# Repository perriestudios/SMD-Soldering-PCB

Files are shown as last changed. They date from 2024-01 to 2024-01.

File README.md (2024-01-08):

# EE201 - Computer Hardware Skills

## SMD Soldering Practice Board

This PCB was designed with the goal of teaching students how to solder surface mount components. 

### Logic
The core logic of the circuit is the logic gates NOT, AND, OR and XOR. There is a multiplexer the outputs of one of these gates to the LED used for indication.

### Inputs
Power supply for the PCB is through a Type-C USB.

There are two tactile switches (push buttons), used to emulate the inputs A and B for the logic gates. The circuit is in active-high configuration with a weak pull-down resistor of 1k. This value was chosen to consolidate the BOM and limit the number of unique resistors(since LEDs also need current limiting resistors).

A DIP Switch is used to set the MUX configuration of Enable, S0 and S1. The other two inputs of the DIP switch can be used as a back up for inputs A and B.

### More SMT Packages Section

This section is used to provide an overview of some commonly available SMD packages of Passives, Transistors and ICs. Students will not solder this, it is just to give them a feel of how big components are.

### Packages that Students will be Soldering

- Resistors: 0805 and 1206
- LED: 1206
- Logic Gates: SOT323
- MUX: SOIC16
- Capacitor - 0603
- Tactile Switches - 6mmx6mm
- DIP Switch - 2.54mm pitch

### Design Choices

In the process of completing this design, there were several tradeoffs and decisions made. The biggest factor influencing the choices was a circuit of reasonable complexity for Sophomores to solder in approximately 1 hour.

- Logic gates were chosen as the design as it would be intuitive and fun. Some of the other ideas considered were a Digital Dice, Digital Modulator(PPM, PWM, PAM), a device that would indicate a threshold (temperature, etc).
- Limited the number of components to 15
- Limited the package size to 0805

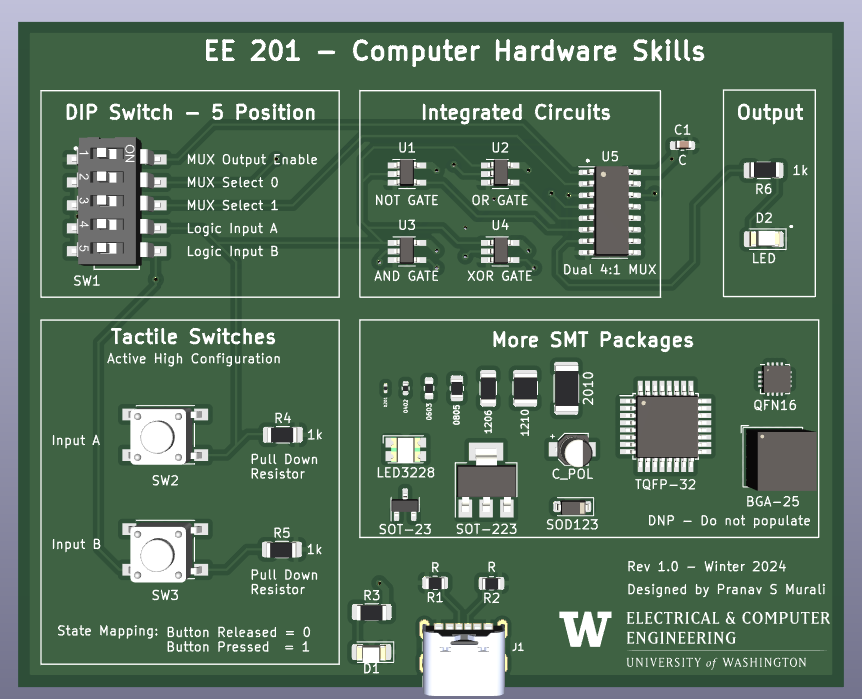
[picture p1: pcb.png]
3D View of the PCB


### Possible improvements

- Wanted to interface an RGB Led, but didn't proceed considering cost and complexity of soldering.
- Find a way to control the routing of inputs of the logic gates. Currently there is only routing over the outputs. The logic gates will be draining power unnecessarily.
- Instead of using an off the shelf IC, one of the gates could be replaced with an actual TTL implementation. NOT gate would be the easiest.

### Acknowledgement

This design was inspired by [Educational Logic Gates PCB](https://www.pcbway.com/project/shareproject/Educational_logic_gates_PCB.html)

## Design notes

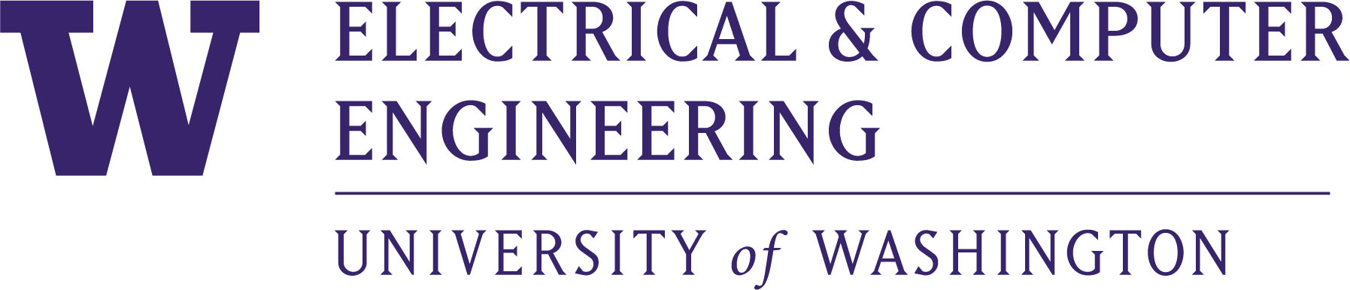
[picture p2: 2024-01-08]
ECE_UW_stack_purp.jpg

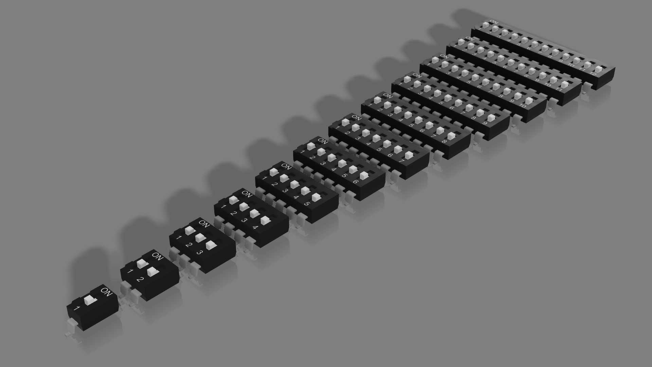
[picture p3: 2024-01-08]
3D Models/smd-dip-switches-1.snapshot.2/SMD DIP SWITCH RENDER.png

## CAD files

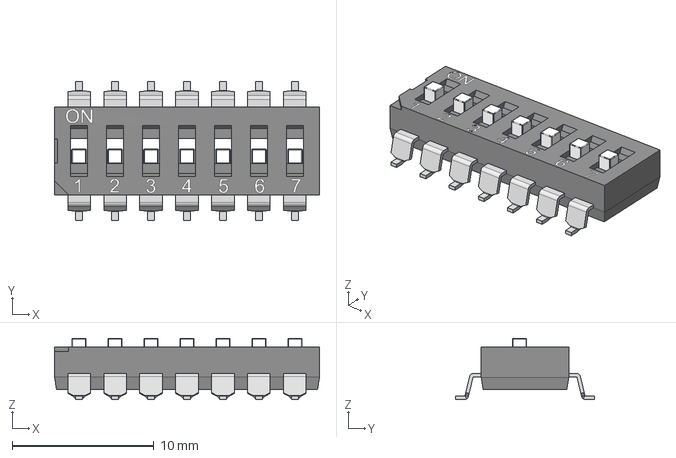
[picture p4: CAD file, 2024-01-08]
3D Models/smd-dip-switches-1.snapshot.2/SMD DIP SWITCH 7P.step
18.7 x 9.80 x 4.32 mm

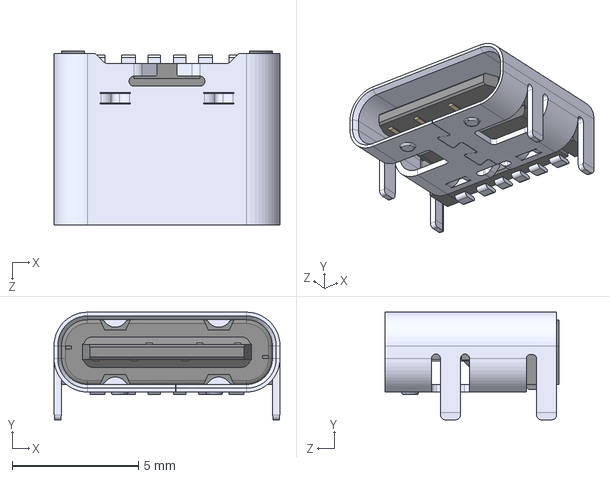
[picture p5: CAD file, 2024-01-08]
3D Models/UJC-HP-3-SMT-TR--3DModel-STEP-56544.STEP
8.94 x 4.26 x 6.90 mm

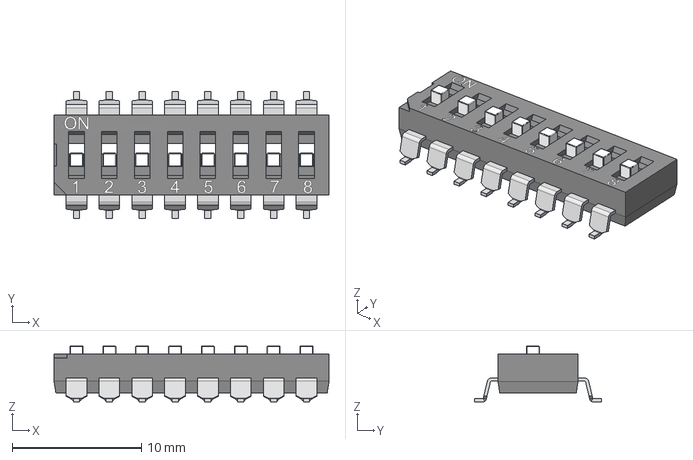
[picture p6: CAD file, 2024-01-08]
3D Models/smd-dip-switches-1.snapshot.2/SMD DIP SWITCH 8P.step
21.3 x 9.80 x 4.32 mm

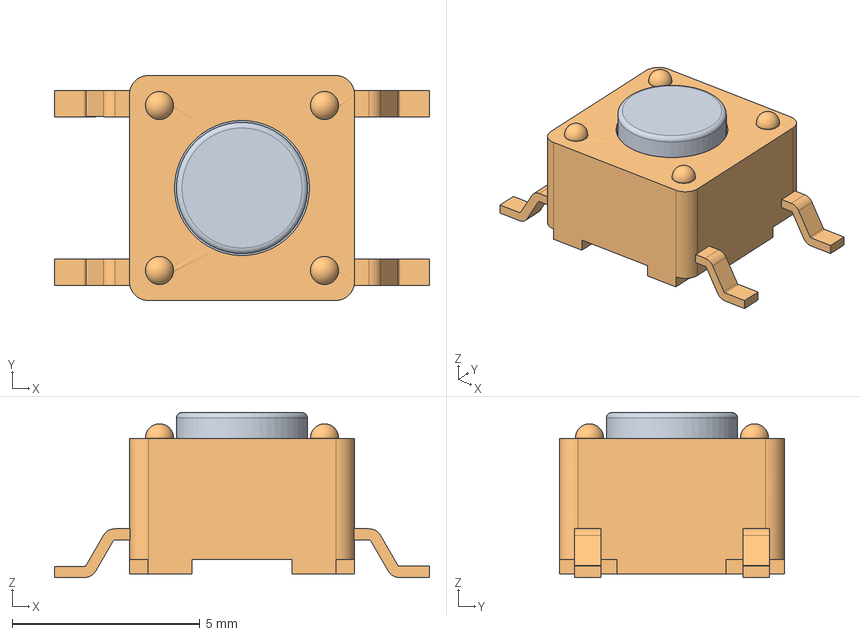
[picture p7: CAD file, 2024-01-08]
3D Models/TL3301NF160QG--3DModel-STEP-520916.STEP
10.0 x 6.00 x 4.40 mm

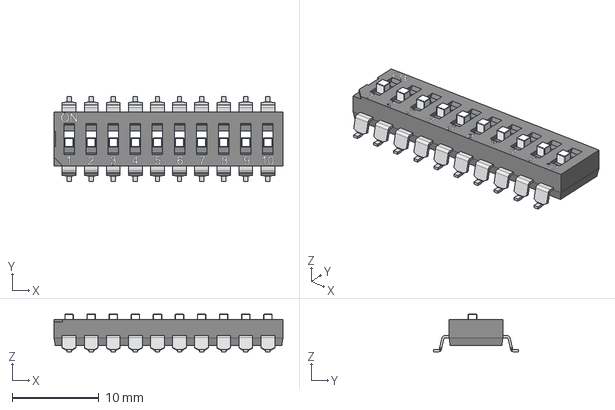
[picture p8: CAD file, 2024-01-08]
3D Models/smd-dip-switches-1.snapshot.2/SMD DIP SWITCH 10P.step
26.3 x 9.80 x 4.32 mm

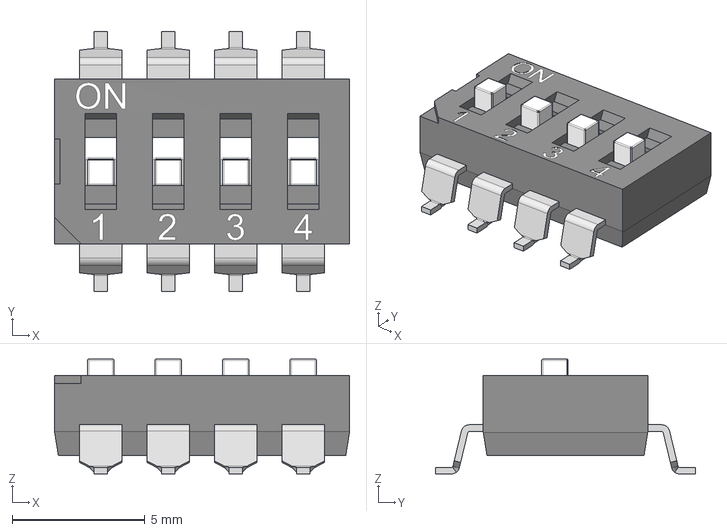
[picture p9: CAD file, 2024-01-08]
3D Models/smd-dip-switches-1.snapshot.2/SMD DIP SWITCH 4P.step
11.1 x 9.80 x 4.32 mm

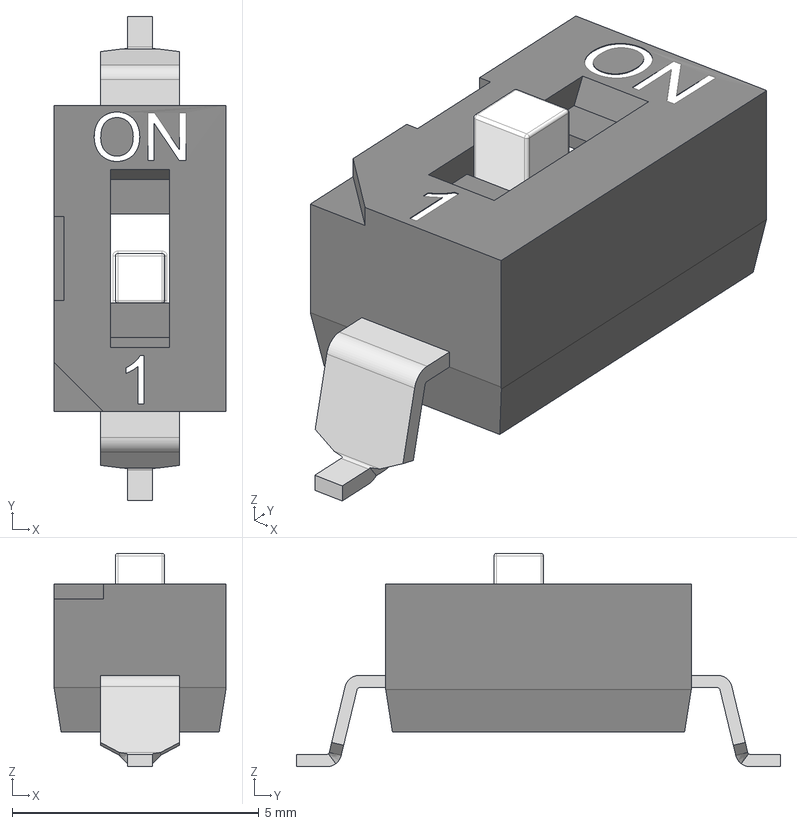
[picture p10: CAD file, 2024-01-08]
3D Models/smd-dip-switches-1.snapshot.2/SMD DIP SWITCH 1P.step
3.48 x 9.80 x 4.32 mm

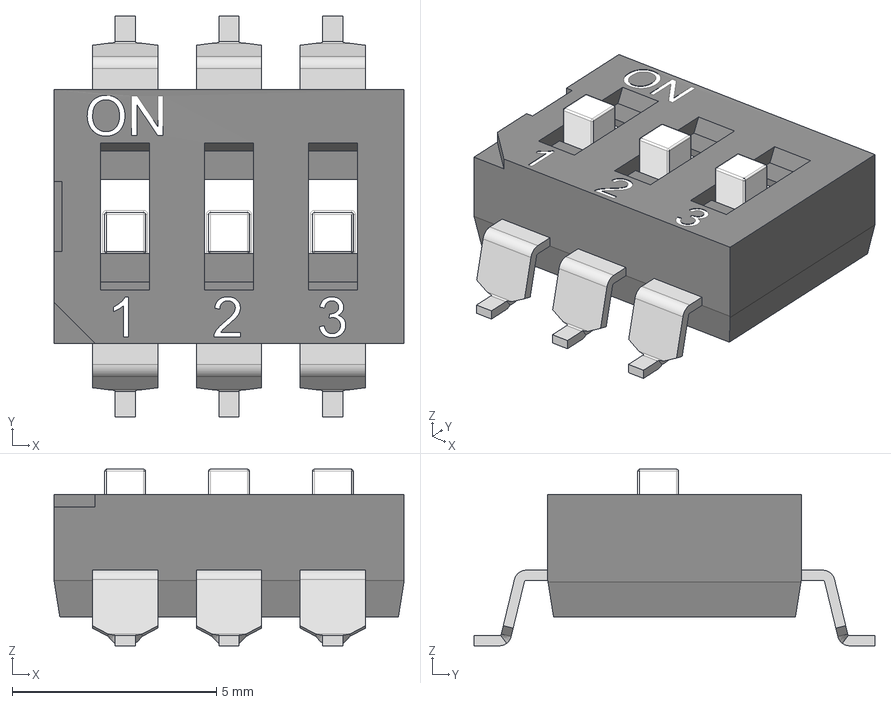
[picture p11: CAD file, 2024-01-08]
3D Models/smd-dip-switches-1.snapshot.2/SMD DIP SWITCH 3P.step
8.56 x 9.80 x 4.32 mm

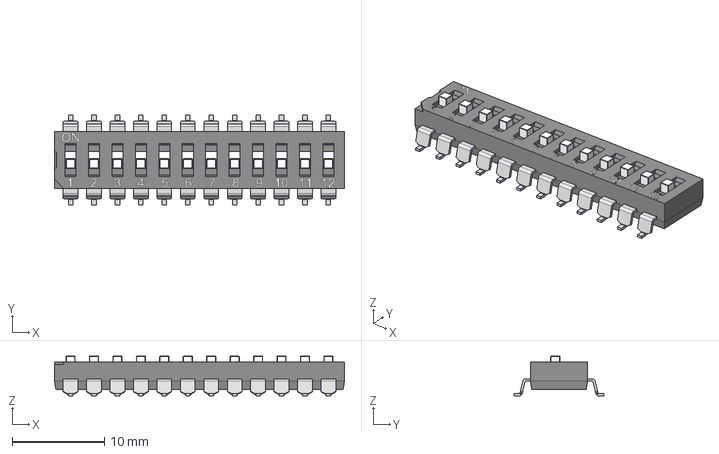
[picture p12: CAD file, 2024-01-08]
3D Models/smd-dip-switches-1.snapshot.2/SMD DIP SWITCH 12P.step
31.4 x 9.80 x 4.32 mm

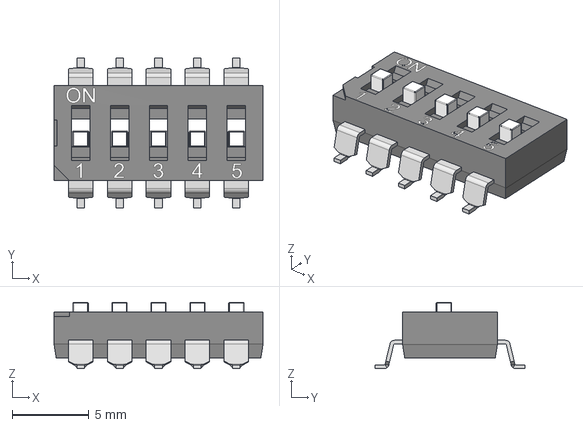
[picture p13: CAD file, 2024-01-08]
3D Models/smd-dip-switches-1.snapshot.2/SMD DIP SWITCH 5P.step
13.6 x 9.80 x 4.32 mm

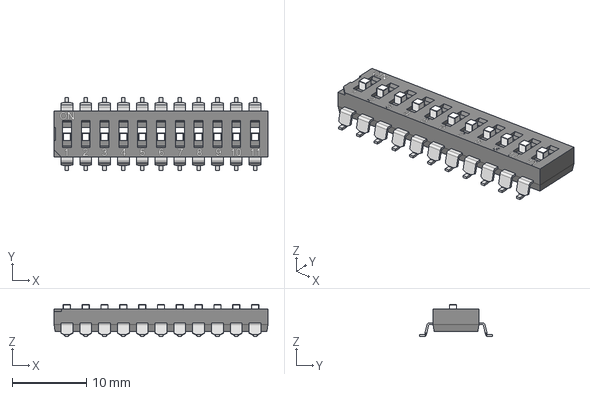
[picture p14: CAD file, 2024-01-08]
3D Models/smd-dip-switches-1.snapshot.2/SMD DIP SWITCH 11P.step
28.9 x 9.80 x 4.32 mm

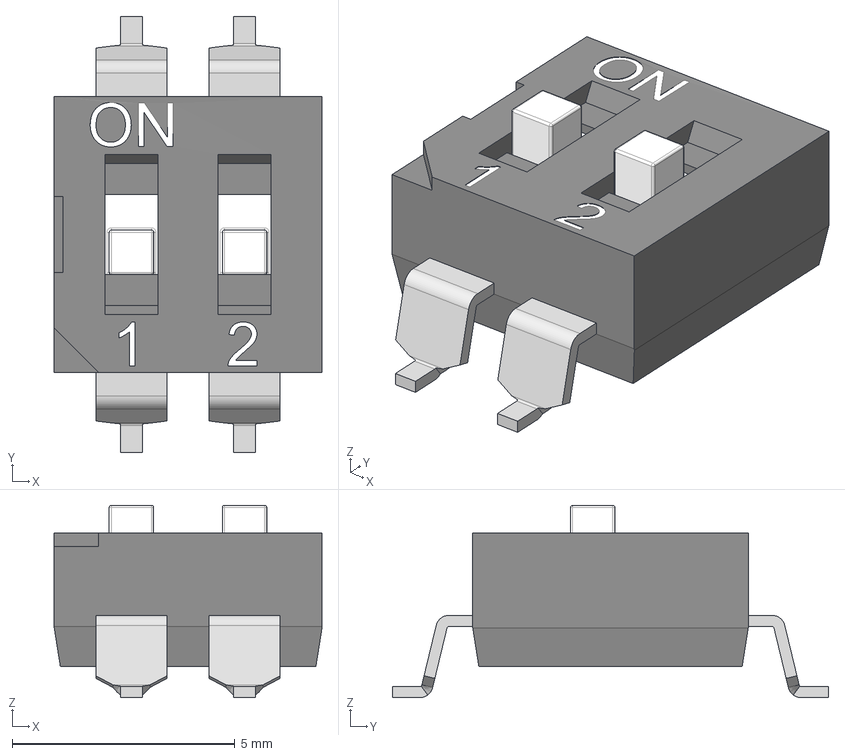
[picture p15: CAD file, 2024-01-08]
3D Models/smd-dip-switches-1.snapshot.2/SMD DIP SWITCH 2P.step
6.02 x 9.80 x 4.32 mm

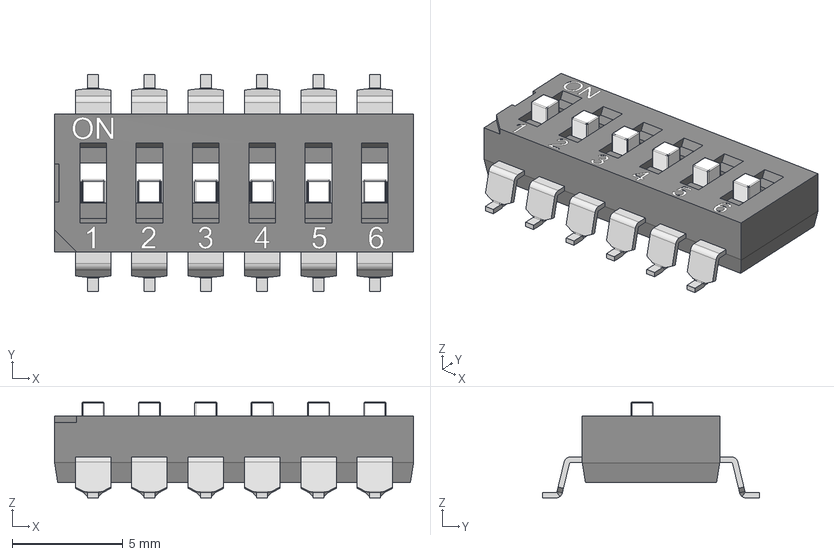
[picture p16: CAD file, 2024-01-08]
3D Models/smd-dip-switches-1.snapshot.2/SMD DIP SWITCH 6P.step
16.2 x 9.80 x 4.32 mm

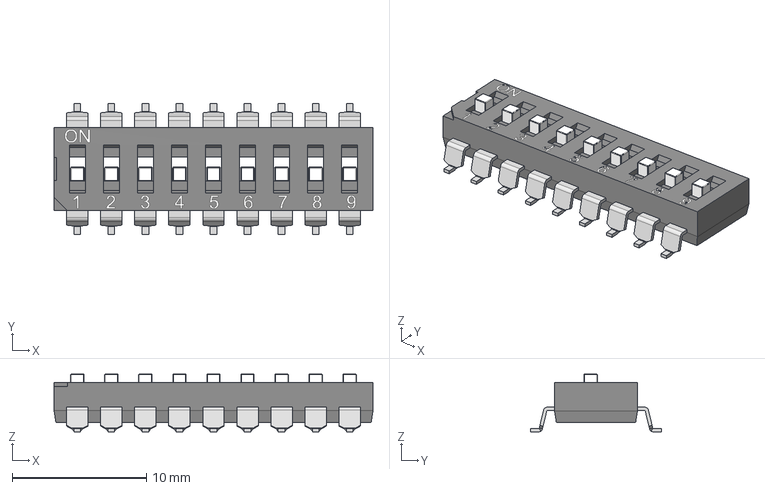
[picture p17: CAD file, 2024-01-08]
3D Models/smd-dip-switches-1.snapshot.2/SMD DIP SWITCH 9P.step
23.8 x 9.80 x 4.32 mm

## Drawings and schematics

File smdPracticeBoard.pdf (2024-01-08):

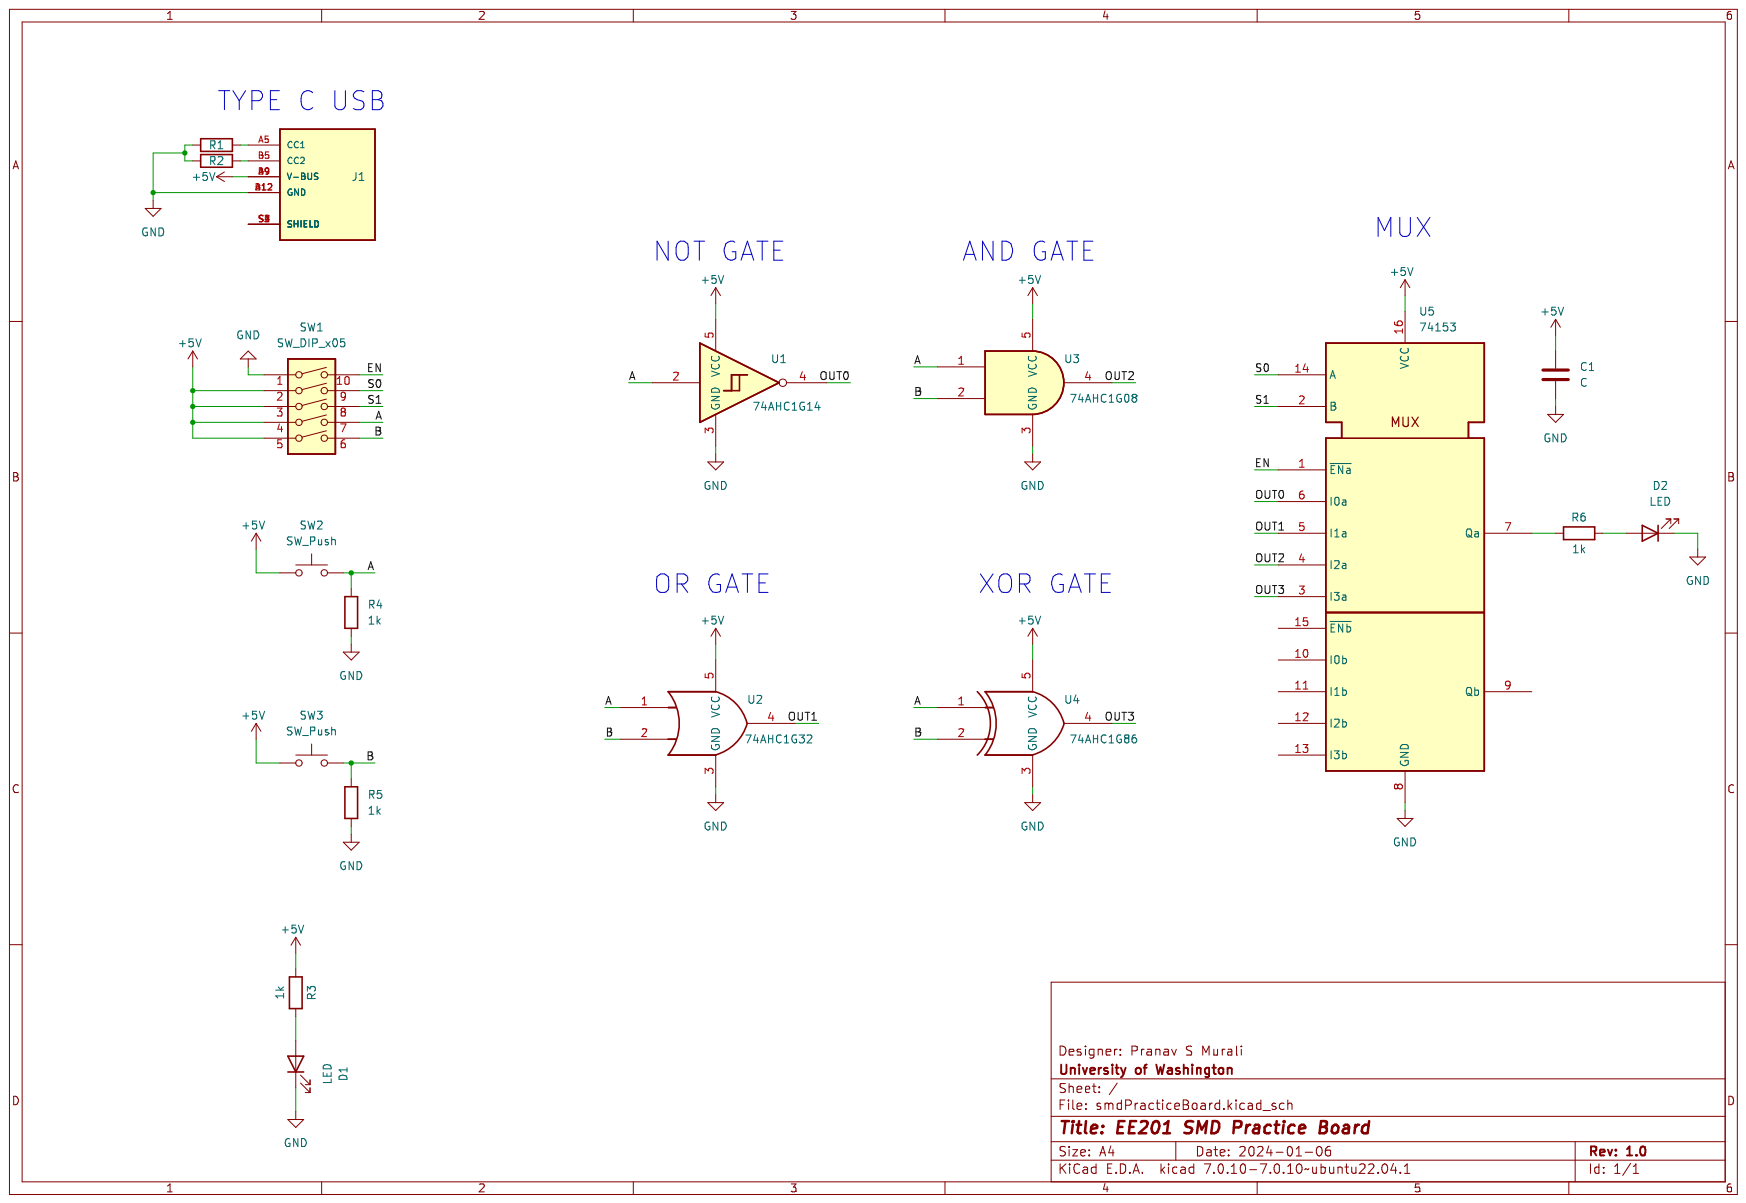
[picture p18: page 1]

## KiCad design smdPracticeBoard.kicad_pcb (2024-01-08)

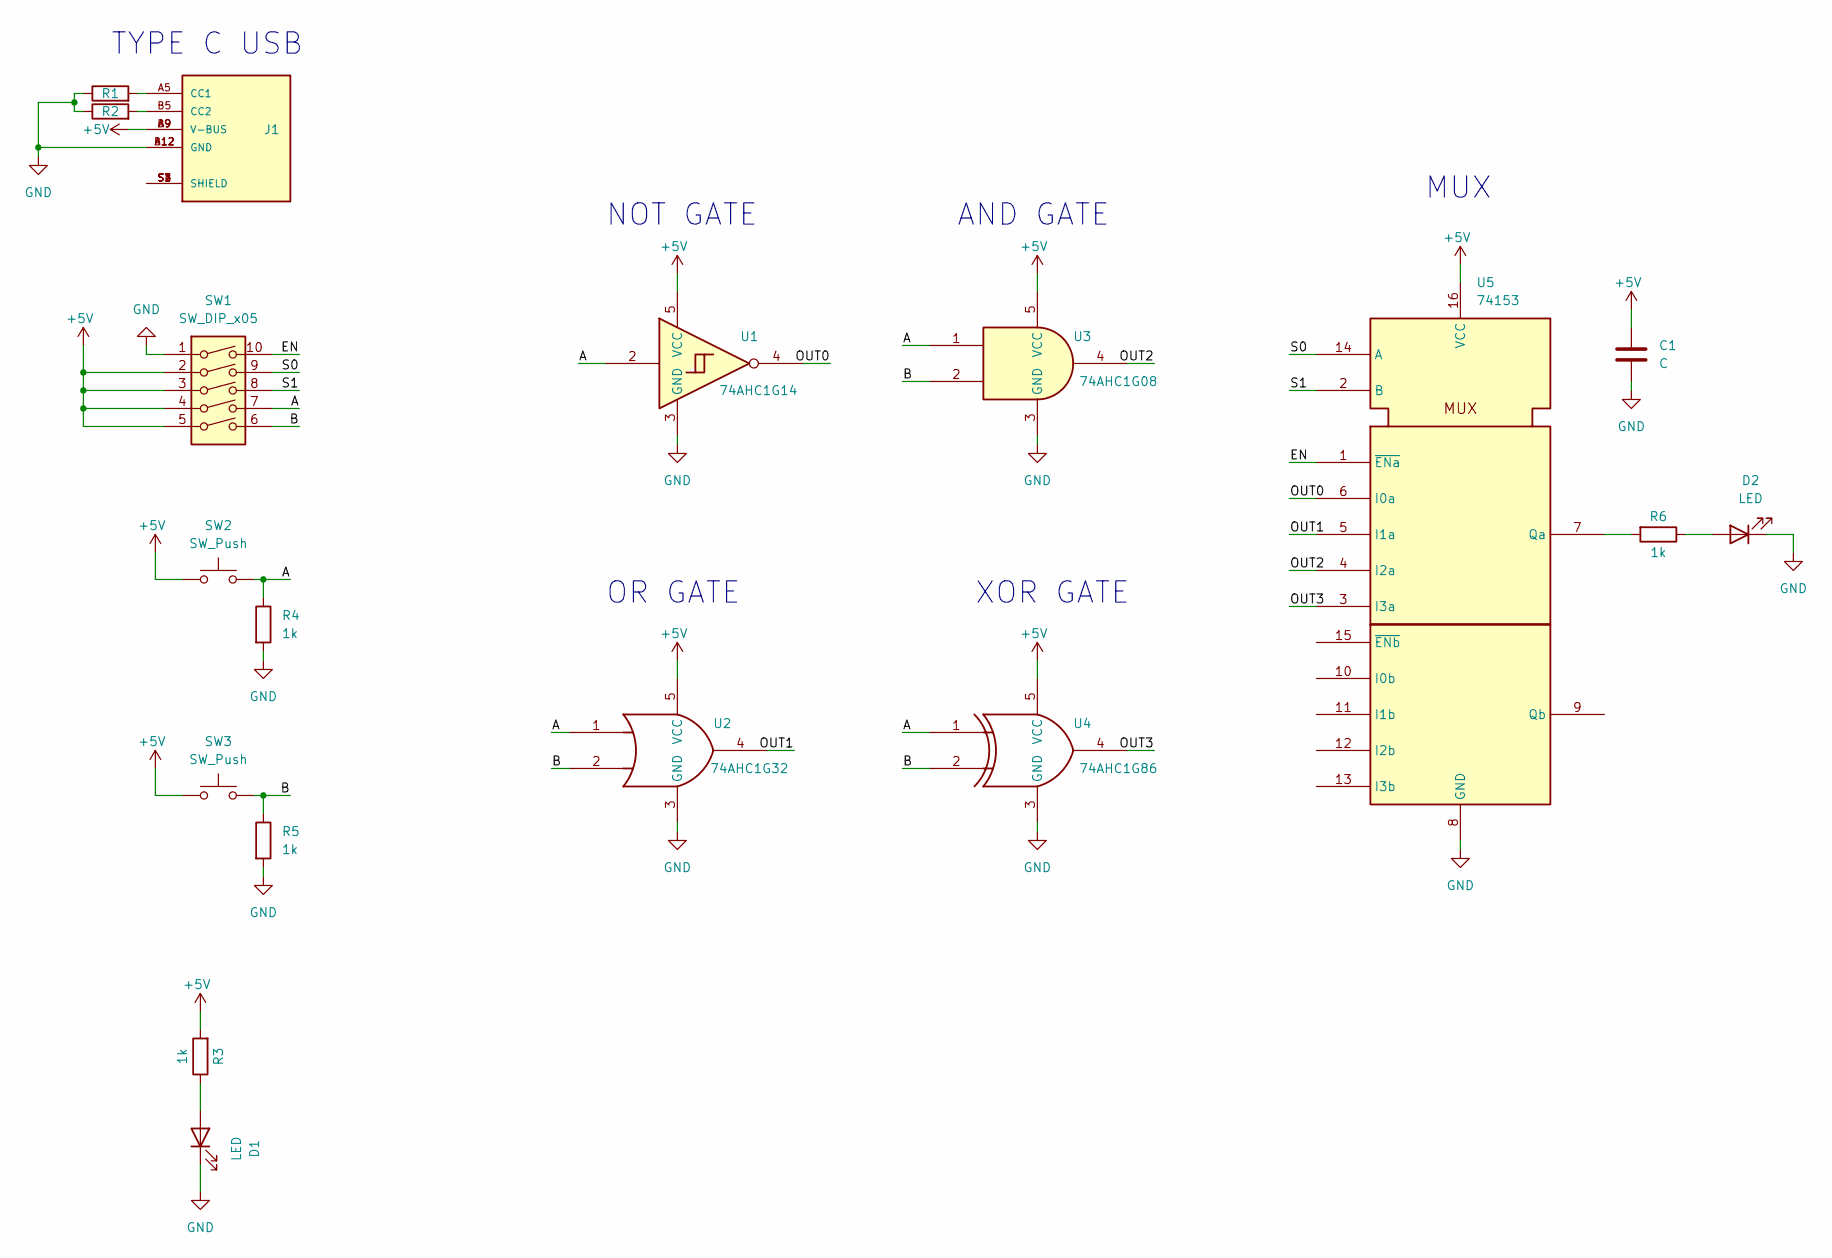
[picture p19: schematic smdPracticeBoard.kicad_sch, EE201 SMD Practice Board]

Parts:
C1: C; C_0603_1608Metric_Pad1.08x0.95mm_HandSolder
D1, D2: LED; LED_1206_3216Metric_Pad1.42x1.75mm_HandSolder
J1: UJC-HP-3-SMT-TR; CUI_UJC-HP-3-SMT-TR; PARTREV 04/30/2020
R1, R2: R; R_0805_2012Metric
R3, R4, R5, R6: 1k; R_1206_3216Metric_Pad1.30x1.75mm_HandSolder
SW1: SW_DIP_x05; CTS-219-5MST-0
SW2, SW3: SW_Push; SW_Push_1P1T_NO_6x6mm_H9.5mm
U1: 74AHC1G14; SOT-23-5_HandSoldering
U2: 74AHC1G32; SOT-23-5_HandSoldering
U3: 74AHC1G08; SOT-23-5_HandSoldering
U4: 74AHC1G86; SOT-23-5_HandSoldering
U5: 74153; SOIC-16_3.9x9.9mm_P1.27mm

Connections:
+5V: C1.1, J1.A9 (V-BUS), J1.B9 (V-BUS), R3.2, SW1.2, SW1.3, SW1.4, SW1.5, SW2.1, SW3.1, U1.5 (VCC), U2.5 (VCC), U3.5 (VCC), U4.5 (VCC), U5.16 (VCC)
/A: R4.1, SW1.7, SW2.2, U1.2, U2.1, U3.1, U4.1
/B: R5.1, SW1.6, SW3.2, U2.2, U3.2, U4.2
/EN: SW1.10, U5.1 (~ENa)
/OUT0: U1.4, U5.6 (I0a)
/OUT1: U2.4, U5.5 (I1a)
/OUT2: U3.4, U5.4 (I2a)
/OUT3: U4.4, U5.3 (I3a)
/S0: SW1.9, U5.14 (A)
/S1: SW1.8, U5.2 (B)
GND: C1.2, D1.1 (K), D2.1 (K), J1.A12 (GND), J1.B12 (GND), R1.1, R2.1, R4.2, R5.2, SW1.1, U1.3 (GND), U2.3 (GND), U3.3 (GND), U4.3 (GND), U5.8 (GND)
unnamed: D1.2 (A), R3.1
unnamed: D2.2 (A), R6.1
unnamed: J1.A5 (CC1), R1.2
unnamed: J1.B5 (CC2), R2.2
unnamed: J1.S1 (SHIELD), J1.S2 (SHIELD), J1.S3 (SHIELD), J1.S4 (SHIELD)
unnamed: R6.2, U5.7 (Qa)

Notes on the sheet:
NOT GATE
OR GATE
MUX
XOR GATE
TYPE C USB
AND GATE

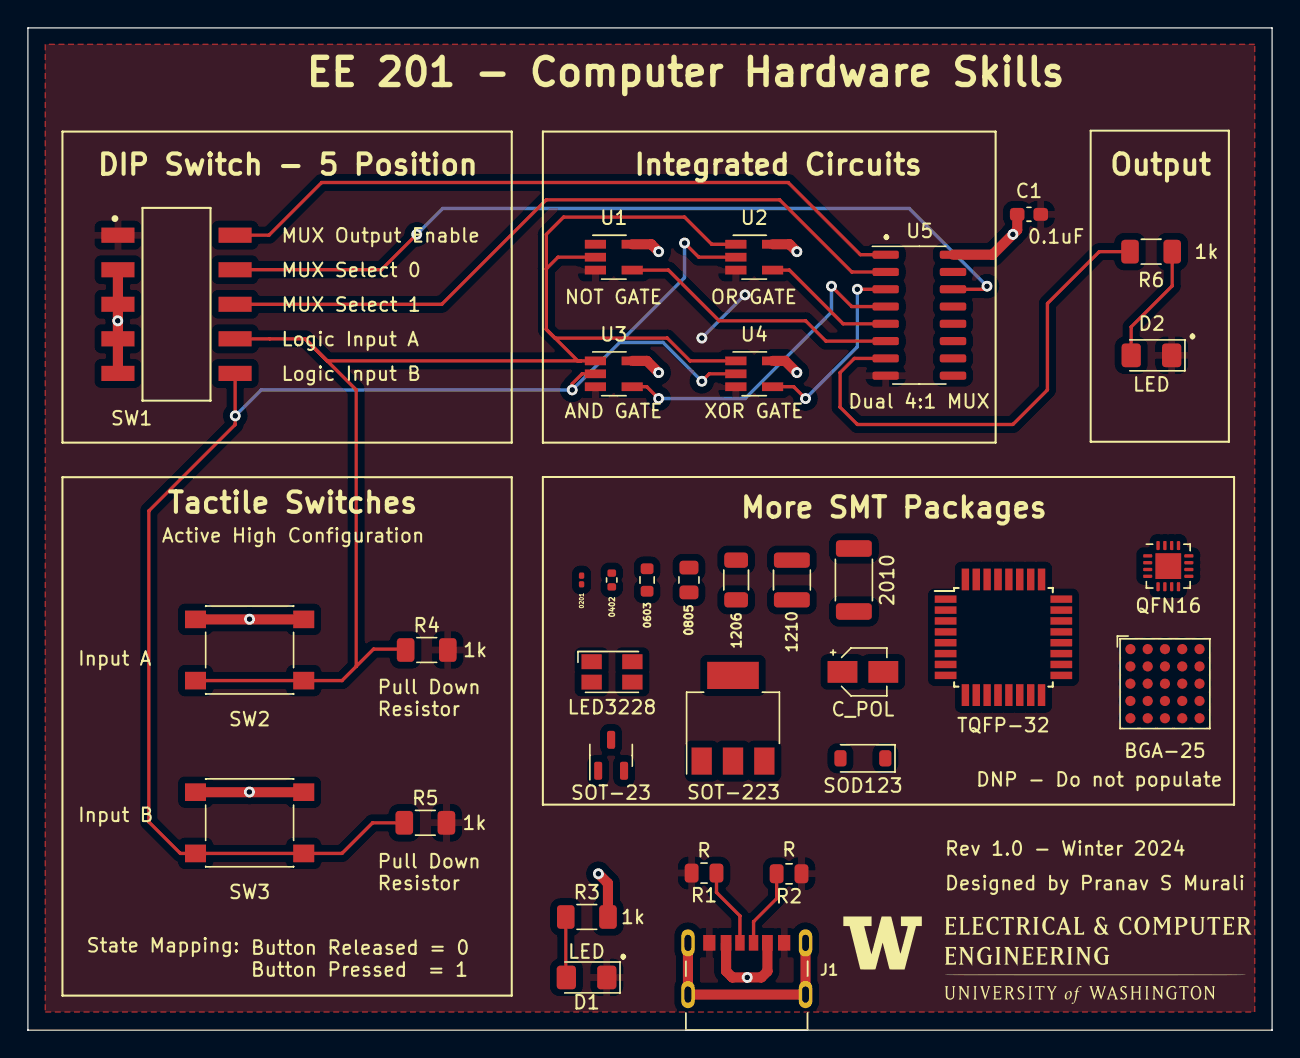
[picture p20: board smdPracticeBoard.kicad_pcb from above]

Board: 2 copper layers, 91.4 x 73.7 mm, 31 parts (0 on the bottom side), 17 nets.

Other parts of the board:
0201: R_0201_0603Metric
0402: R_0402_1005Metric
0603: R_0603_1608Metric
0805: R_0805_2012Metric
1206: R_1206_3216Metric
1210: R_1210_3225Metric
2010: R_2010_5025Metric
BGA-25: BGA-25_6.35x6.35mm_Layout5x5_P1.27mm
C_POL: CP_Elec_3x5.3
LED3228: LED_Avago_PLCC4_3.2x2.8mm_CW
QFN16: QFN-16-1EP_3x3mm_P0.5mm_EP1.9x1.9mm
SOD123: D_SOD-123
TQFP-32: TQFP-32_7x7mm_P0.8mm
